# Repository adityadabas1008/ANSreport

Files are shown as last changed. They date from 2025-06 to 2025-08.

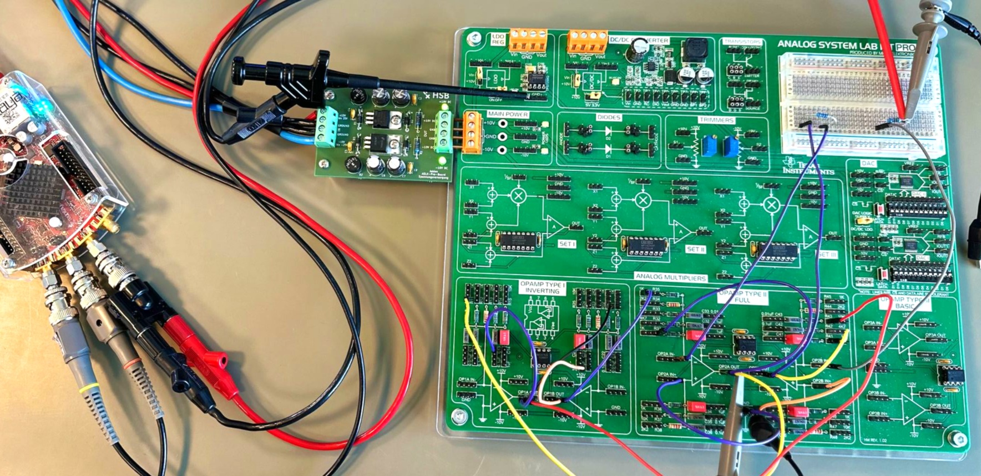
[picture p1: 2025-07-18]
_manuscript/images/Realaufbau.jpg

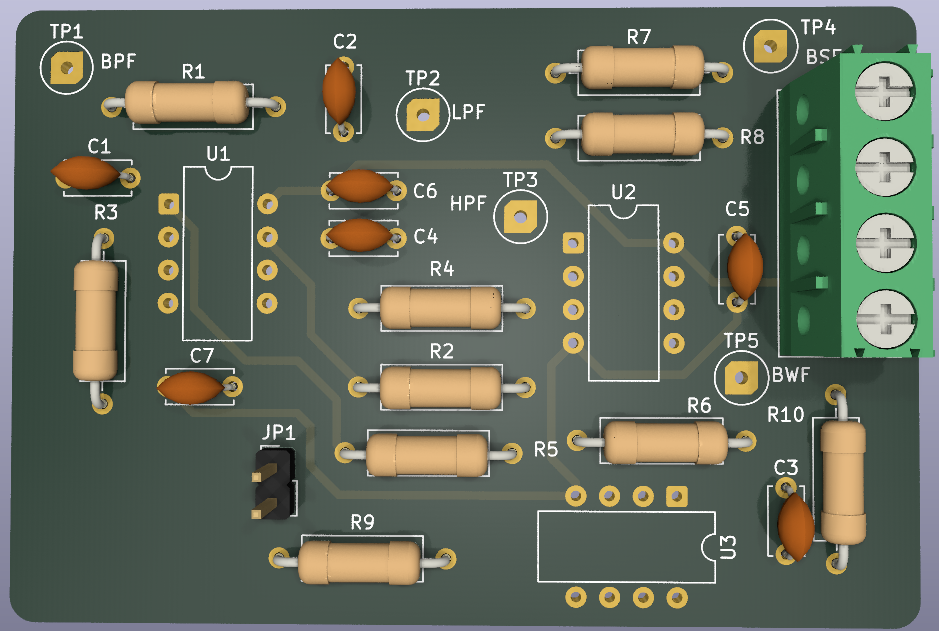
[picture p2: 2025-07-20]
_manuscript/images/pcbv1.png

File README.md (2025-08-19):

# ANSreport

Hello there! Welcome to the ANSreport repository.

This repository is a combined work of the students of the course "Analoge Schaltungen" from the Hochschule Bremen, under the mentorship of **Prof. Dr. Mirco Meiners**.

The contributors are:
- Aditya Dabas
- Adrian Jauch
- Mohamad Wehbi

What you see here is a quarto report of a project from the 'Texas Instruments Analog Circuits Lab Kit' manual.

The project aimed at building deeper understanding of analog circuits using the universal biquad filter design.
Here, we implemented the second order biquad filter in three different stages:
1. **The theory level**: Here, we explored the ideal world of Electronics by simulating the circuit in KiCAD.
2. **Filter on a discrete circuit design**: After that the circuit was build on the lab board of ASLK using jumper wires, was somewhat imperfect, but still worked.
3. **The integrated PCB Design**: Then we wanted to explore the PCB design of the circuit, so we designed the biquad filter on a PCB, in a compact form and checked the functionality in the lab, we also tried to expand the circuit by adding another order to our second order filter, by cascading a second order filter to another butterworth filter to get a third order filter and a cleaner curve.

Now, its upto you to explore the interesting results we got in the ideal world and the real world of electronics.
Another question would be, were we able to successfully cascade the second order filter to a third order filter to get the butterworth output ? was it successful on the compact PCB we designed ?

Run the report to find out!

Please note that the report is in German, as it was a project for a German course.

## How to run the report
1. Clone the repository as it is.
2. Choose the editor of your choice, e.g. [VSCode](https://code.visualstudio.com/).
3. Make sure you have [quarto](https://quarto.org/docs/get-started/) installed.
4. Just render the index.qmd file in the editor.

Voila! You should see the report in your browser.

Thank you for your interest in our project!

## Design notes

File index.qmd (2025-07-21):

---
title: "Entwurf und PCB Design eines universellen Biquad Filters"
author: 
  - name: Aditya Dabas
    orcid: 0009-0001-5679-9910
    email: adabas@stud.hs-bremen.de
    corresponding: true
    roles: "Lead author"
    affiliation: Hochschule Bremen - City University of Applied Sciences (HSB)

  - name: Mohamad Wehbi
    orcid: 
    email: mwehbi@stud.hs-bremen.de
    corresponding: true
    roles: "Lead author"
    affiliation: Hochschule Bremen - City University of Applied Sciences (HSB)

  - name: Adrian Jauch
    orcid: 
    email: ajauch@stud.hs-bremen.de
    corresponding: false
    roles: "Lead author"
    affiliation: Hochschule Bremen - City University of Applied Sciences (HSB)

affiliation:
  -  name: Hochschule Bremen - City University of Applied Sciences (HSB)
     city: Bremen
     state: Germany
     url: https://www.hs-bremen.de  

keyword:
  - Filter Design 
  - PCB

abstract: |
  In diesem Projekt wurde ein universeller Biquad-Filter entworfen und als Leiterplatte (PCB) umgesetzt. Ziel war es, die theoretischen Grundlagen zu analysieren, verschiedene Filtertypen zu simulieren und die praktische Realisierung zu dokumentieren. Die Charakterisierung und Messauswertung des aufgebauten Filters zeigen die Übereinstimmung zwischen Theorie und Praxis. Der gesamte Entwicklungsprozess – von der Schaltungsauslegung bis zum fertigen PCB – wird nachvollziehbar dargestellt.

date: last-modified
bibliography: references.bib
# csl: ieee-with-url.csl
# fig-numbering: true 
---

{{< include content/_sec_Motivation.qmd >}}
{{< include content/_sec_Theorie.qmd >}}
{{< include content/_sec_Filter.qmd >}}
{{< include content/_sec_Charakterisierung.qmd >}}
{{< include content/_sec_Messauswertung.qmd >}}
{{< include content/_sec_PCB_Entwurf.qmd >}}
{{< include content/_sec_Fazit.qmd >}}
{{< include content/references.qmd >}}

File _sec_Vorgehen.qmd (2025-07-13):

# Vorgehen

Was haben wir von anfang an bis jetzt gemacht ?

1. Anti Aliasing Fliter
2. Filter entwurf mit RLC Glied, TP, HP, BP
3. Einführung in die Biquads
4. ASLK Lab Manual - Labor 4 gelesen, Spezifikation gelesen, Schaltung gesehen, Ziel des Projekts festgelegt
5. Spezifikation für die Schaltung: Durch Kreisfrequenzen R , C werte und Kreisfrequenz f berechnet, Güte Faktor miteinbezogen 
6. Simulation auf KiCAD durchgeführt, Plots mit dem Manual verglichen
7. Schaltungsaufbau auf dem ASLK Board mit Kabeln
8. RedPitaya integriert für Messung und Auswertung der Schaltung (Bode-Plot und Messwerte)
9. Schaltungsverhalten unerwartet, dann die Schaltung überprüft (gemerkt: Kabelnstecken ist eine Fehlerquelle)
10. Messung erneut düchgeführt, mussten nochmal schaltüng überprüfen
11. Das Problem war ASLK Board und nicht der Aufbau, rausgefunden indem: die Schaltung vom Laboring überprüfen lassen
12. Die Schaltung neu aufbaut, mit dem neuen Board und ohne Kabeln zu verlängern (keine 2 Kabeln zusammengesteckt)
13. Nochmal gemessen und erwartete Ergebnisse bekommen. (Bestätigt - Board war das Problem)
14. Messwerte aufgenommen mit adäquat Datenmanagement und entsprechende Spezifikationen
15. Nach ASLK Manual Aufgaben gemacht und die Messwerte aufgenommen, leichte änderung an der Schaltung je nach Aufgabenstellung
16. Bode Plot analysiert um Verhalten von Filtern zu überprüfen, -20dB Dämpfung in der Amplitude rausgefunden
17. Fehler Suche: Wiederstände überprüft und die auf dem Board gemessen mit Multimeter, festgestellt: R6 war 10k Ohm anstatt 1k Ohm
18. RedPitaya auf HV gestellt, um Peak Messwerte richtig zu bekommen
19. Messungen erneut aufgenommen, Fehler beseitigt
20. Schaltung mit einer weiteren Ordnung Erweitert: Butterworth Filter in der Schaltung eingebaut, Übertragungsfunktionen hergeleitet
21. Die erweiterte Schaltung simuliert: Erwartete Ergebnisse bekommen
22. Schaltung auf dem Steckbrett entsprechend der Simulation erweitert und gemessen: Auch gute Ergebnisse bekommen
23. Schaltung war jetzt bereit für ein Leiterplattendesign
24. 3 Variante von PCB design mit Verbesserungen in jeder Transition
25. PCB Design erwitert für 2 Schaltungmöglichkeiten
26. Design Überprüfen lassen vom LaborING und dann die Platine bestellt
27. Platine gefertigt, gemessen, Messwerte für den Vergleich mit Redpitaya aufgenommen

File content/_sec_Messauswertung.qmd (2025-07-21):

# Messung und Analyse

Nachdem wir die Biquad-Filter-Schaltung bereits erfolgreich auf dem ASLK Pro Board aufgebaut haben, lag der Fokus dieses Abschnitts auf der Durchführung der Messungen und der anschließenden Auswertung der Ergebnisse. Ziel war es, die realen Frequenzgänge der verschiedenen Filtertypen experimentell zu erfassen und diese mit den zuvor durchgeführten Simulationen zu vergleichen.

## Messungsschritte {.unnumbered}

Für die experimentelle Ermittlung des Frequenzgangs wurde die Schaltung mithilfe der grafischen Oberfläche des Red Pitaya vermessen.

Die so gewonnenen Messdaten wurden im Anschluss exportiert und zur weiteren Analyse mit einem eigens entwickelten Python-Skript ausgewertet. Dadurch war es möglich, die Amplituden- und Phasengänge der real aufgebauten Schaltung systematisch mit den Simulationskurven zu vergleichen.

## Vergleich Simulation vs. Diskret
Zur Bewertung der praktischen Umsetzung wurden die Messergebnisse der real aufgebauten Schaltung mit den zuvor durchgeführten Simulationen verglichen. Für beide Gütefaktoren ($Q=1$ und $Q=10$) wurden jeweils die Frequenzgänge der vier Filtertypen (Tiefpass, Hochpass, Bandpass und Bandsperre) aufgenommen und grafisch gegenübergestellt.

### Für $Q=1$ {.unnumbered}

### -Bandpass {.unnumbered}

Bode-Plot Vergleich des simulierten- und des auf dem Board Bandpassfilters für $Q = 1$.

Die Simulation-Messung liefert einen klar definierten Resonanzpeak mit sehr gleichmäßigen Flanken. Die diskrete Variante zeigt den Peak geringfügig verschoben und weist an den Flanken kleine Unregelmäßigkeiten auf, wodurch der Verlauf etwas unschärfer erscheint.

### -Bandstop {.unnumbered}

Bode-Plot Vergleich des simulierten- und des auf dem Board Bandstopfilters für $Q = 1$.

Der Einbruch der Bandsperre zeichnet sich durch eine besondere Tiefe und flache, saubere Flanken aus. Bei einem diskreten Aufbau ist die Dämpfung durchaus vergleichbar, jedoch treten an den Rändern leichte Sprünge und geringfügige Ungenauigkeiten auf.

### -Hochpass {.unnumbered}

Bode-Plot Vergleich des simulierten- und des auf dem Board Hochpassfilters für $Q = 1$.

Der Hochpass auf der Simulation steigt bis zur Eckfrequenz ohne Störungen an und fällt danach konstant mit –20 dB/Dekade ab. Der diskrete Versuchsaufbau hinkt diesem Anstieg minimal hinterher und zeigt punktuelle Ausreißer bei etwa $50 Hz$ und $100 Hz$.

### -Tiefpass {.unnumbered}

Bode-Plot Vergleich des simulierten- und des auf dem Board Tiefpassfilters für $Q = 1$.

Beim Tiefpass fällt die Simulation-Kurve bis zur Eckfrequenz ideal flach ab und nimmt dann homogen –40 dB/Dekade an. Die diskrete Schaltung weist um die Eckfrequenz ein leichtes Überschwingen und vereinzelt kleine Unebenheiten im Sperrbereich auf.

### Für $Q=10$ {.unnumbered}

### -Bandpass {.unnumbered}

Bode-Plot Vergleich des simulierten- und des auf dem Board Bandpassfilters für $Q = 10$.

Der starke Resonanzpeak ist deutlich ausgeprägt, jedoch sehr gleichmäßig. Im diskreten Aufbau fällt der Peak minimal tiefer aus, wirkt aber an der Spitze etwas unruhig und leicht gezackt.

### -Bandstop {.unnumbered}

Bode-Plot Vergleich des simulierten- und des auf dem Board Bandstopfilters für $Q = 10$.

Bei der Bandsperre ist der Einbruch auf der Board geringfügig flacher, dafür allerdings äußerst stabil und glatt. Die Simulation Kurve erreicht eine etwas tiefere Dämpfung.

### -Hochpass {.unnumbered}

Bode-Plot Vergleich des simulierten- und des auf dem Board Hochpassfilters für $Q = 10$.

Die Simulation zeigt einen idealen Anstieg bis zur Grenzfrequenz und einen konstanten Verlauf darüber hinaus. Im diskreten Aufbau ist der Anstieg etwas flacher, und es treten leichte Unregelmäßigkeiten im Bereich um $100\,\mathrm{Hz}$ auf.

### -Tiefpass {.unnumbered}

Bode-Plot Vergleich des simulierten- und des auf dem Board Tiefpassfilters für $Q = 10$.

Die Simulation zeigt einen idealen Abfall nach der Grenzfrequenz mit einer Steilheit von –40 dB/Dekade. Im diskreten Aufbau ist der Abfall etwas weniger steil, und es treten leichte Unregelmäßigkeiten im Sperrbereich auf.

## Interpretation der Messergebnisse

Insgesamt zeigen die Plots, dass die gemessenen Frequenzgänge der realen Schaltung den simulierten Kurven in ihrem grundsätzlichen Verlauf gut entsprechen. Die charakteristischen Eigenschaften der jeweiligen Filtertypen (Bandpass, Bandsperre, Hochpass, Tiefpass) sind sowohl in Simulation als auch in der Messung klar erkennbar.

Die beobachteten Abweichungen zwischen Simulation und Messung sind hauptsächlich auf Bauteiltoleranzen sowie Einflüsse der verwendeten Messkabel zurückzuführen. Nicht ideale Kontakte, Toleranzen der Bauteile oder Kabel können das Messergebnis beeinflussen. Zudem können Unterschiede in der Frequenzauflösung oder fehlende Messwerte in bestimmten Bereichen zu Abweichungen führen, insbesondere wenn Messung und Simulation nicht exakt dieselben Frequenzen abdecken.

Zusammenfassend bestätigen die Messergebnisse die prinzipielle Funktionsweise der Filter, zeigen aber auch die Grenzen idealisierter Simulationen im Vergleich zur realen Schaltungspraxis auf.

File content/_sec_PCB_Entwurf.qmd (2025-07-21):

# Umsetzung als Leiterplatte
Die Umsetzung der Biquad-Schaltung auf eine gedruckte Leiterplatte (PCB) verfolgt mehrere Ziele: 
Erstens erhöht eine professionelle Leiterplatte die mechanische Stabilität und Wiederholgenauigkeit im Vergleich zu Jumperkabel-Versuchen. 
Zweitens minimiert eine sorgfältig geroutete Platine parasitäre Effekte (Leitungsinduktivitäten, -kapazitäten), die bei langen, unkontrollierten Kabelwegen auftreten. 
Drittens erlaubt die PCB eine kompakte, übersichtliche Integration aller Filterzweige, sodass verschiedene Eckfrequenzen oder Gütefaktoren per Jumper umgeschaltet werden können, ohne das Board komplett neu aufzubauen.

## Vorgehensweise im Layoutprozess

1. **Auswahl der Basis-Topologie**  
   Zunächst wurde die einfachste Biquad-Schaltung für Güte $Q=1$ mit Eckfrequenz $\approx 160\,\mathrm{Hz}$ in KiCad aufgebaut.

2. **Footprint-Zuordnung**  
   Für alle Bauteile (Operationsverstärker im DIL-Sockel, Widerstände, Kondensatoren, Jumper) wurden passende Footprints manuell ausgewählt. DIL-Sockel ermöglichen den einfachen Ein- und Ausbau der OP-Amps.

3. **Erweiterung um Schaltoptionen**  
   Um Messungen bei zwei unterschiedlichen Gütefaktoren und zwei Eckfrequenzen zu ermöglichen, wurden Jumper-Pads vorgesehen, mit denen man:  
   - zwischen $Q=1$ und $Q=10$ umschalten  
   - die Eckfrequenz durch Parallelschaltung unterschiedlicher RC-Glieder wechseln  
   - den LPF-Ausgang als Eingang für die 3. Ordnung–Butterworth-Stufe aktivieren kann  

4. **Platzoptimierung**  
   Das erste Layout maß ca. 5 cm × 7 cm (siehe @fig-pcbv1), war aber zu unflexibel. Das erweiterte Design kam auf 5 cm × 8 cm(siehe @fig-pcbs). Dabei war uns wichtig:  
   - **Bauteilenah**: Kurze Verbindungen zwischen OP-Amp-Pins und zugehörigen RC-Netzwerken reduzieren parasitäre L- und C-Effekte.  
   - **Abwinkelung**: Leiterbahnen wurden nur mit maximal $45^\circ$-Ecken geroutet, um Reflexionen und Signalverzerrungen bei höheren Frequenzen zu minimieren.  
   - **Layernutzung**: Das Top-Layer für Signal- und Strompfade, das Bottom-Layer vollständig als durchgehende Massefläche („Ground Plane“) reserviert. So entfallen separate GND-Drähte. 
   - **Decoupling**: An jeder Spannungsversorgung des TL082 wurde $100\,\mathrm{nF}$ Kondensatoren nahe den OP-Amp-Pins platziert, um Versorgungsspannungsspitzen und Rauschen zu unterdrücken.

   PCB-Design Version 1

---

### Design-Verbesserungen und Begründungen {.unnumbered}

1. **Bauteilwertebeschriftung**  
   Jeder Widerstand und Kondensator erhielt eine Referenz („R1“, „C3“) und einen Wertaufdruck auf der Silkscreen-Schicht. Fehlt dies, kann beim Bestücken leicht verwechselt werden.

2. **Fehlender GND-Pins**  
   Auf dem PCB fehlte Ground-Pins. Dadurch war es schwer, während der Messung eine sichere Masseverbindung herzustellen. Wir haben das provisorisch durch manuelles Bohren von zwei Löchern und den Einbau von Pins zur Groundplane behoben.

3. **Jumper als Fehlerquelle**  
   Die mechanischen Jumper auf dem Board sind zwar flexibel, können aber ähnliche Störeffekte wie Jumperkabel verursachen und Messungenauigkeiten einführen.

::: {#fig-pcbs layout-ncol=2}

Fertiges PCB-Design

Fertige PCB

Fertige Bi-Quad Filter Platine
:::

### Zusammenfassung und Ausblick {.unnumbered}

Mit diesem PCB-Design haben wir eine kompakte, reproduzierbare Plattform geschaffen, um Biquad-Filter mit variabler Güte und Eckfrequenz zu charakterisieren und bei Bedarf um eine Butterworth-Stufe 3. Ordnung zu ergänzen. 
Für künftige Revisionen empfehlen sich:  
- Vollständige Beschriftung aller Werte auf der Platine  
- Einheitliche GND Pins 
- Integration von SMD-Schaltern statt Jumpern 

Damit wird die Platine für die Lehrzwecke gut geeignet.

## Messungen an der PCB-Schaltung

Im Anschluss an das Layout und die Fertigung der Platine wurden die Übertragungs­funktionen aller Filterausgänge mit dem Red Pitaya Mess­system aufgenommen. Die Signale wurden über einen Frequenz­sweep für verschiedene Frequenzen eingespeist und die Amplituden- sowie Phasengänge mit einem eigens entwickelten Python-Skript ausgewertet und geplottet.  

## Vergleich: Diskret vs. PCB {.unnumbered}

Im Folgenden sind die Bode-Diagramme der diskreten Versuchsaufbauten (auf dem ASLK PRO Board mit Jumperkabeln) gegenüber den Messergebnissen der fertigen PCB-Schaltung dargestellt. Dieser Vergleich zeigt, inwieweit das PCB-Layout die Filtercharakteristik stabilisiert. 

### Für \(Q = 1\) {.unnumbered}

### Bandpass {.unnumbered}

Bode-Plot Vergleich des auf dem Board- und des auf dem PCB Bandpassfilters für \(Q = 1\).

Die PCB-Messung liefert einen klar definierten Resonanzpeak mit sehr gleichmäßigen Flanken. Die diskrete Variante zeigt den Peak geringfügig verschoben und weist an den Flanken kleine Unregelmäßigkeiten auf, wodurch der Verlauf etwas unschärfer erscheint.

### Bandstop {.unnumbered}

Bode-Plot Vergleich des auf dem Board- und des auf dem PCB Bandstopfilters für \(Q = 1\).

Der Einbruch der Bandsperre auf der Platine zeichnet sich durch eine besondere Tiefe und flache, saubere Flanken aus. Bei einem diskreten Aufbau ist die Dämpfung durchaus vergleichbar, jedoch treten an den Rändern leichte Sprünge und geringfügige Ungenauigkeiten auf.

### Hochpass {.unnumbered}

Bode-Plot Vergleich des auf dem Board- und des auf dem PCB Hochpassfilters für \(Q = 1\).

Der Hochpass auf der PCB steigt bis zur Eckfrequenz ohne Störungen an und fällt danach konstant mit –20 dB/Dekade ab. Der diskrete Versuchsaufbau hinkt diesem Anstieg minimal hinterher und zeigt punktuelle Ausreißer bei etwa 50 Hz und 100 Hz.

### Tiefpass {.unnumbered}

Bode-Plot Vergleich des auf dem Board- und des auf dem PCB Tiefpassfilters für \(Q = 1\).

Beim Tiefpass fällt die PCB-Kurve bis zur Eckfrequenz ideal flach ab und nimmt dann homogen –40 dB/Dekade an. Die diskrete Schaltung weist um die Eckfrequenz ein leichtes Überschwingen und vereinzelt kleine Unebenheiten im Sperrbereich auf.

---

### Für \(Q = 10\) {.unnumbered}

### Bandpass {.unnumbered}

Bode-Plot Vergleich des auf dem Board- und des auf dem PCB Bandpassfilters für \(Q = 10\).

Der starke Resonanzpeak der Platine ist deutlich ausgeprägt, jedoch sehr gleichmäßig. Im diskreten Aufbau fällt der Peak minimal höher aus, wirkt aber an der Spitze etwas unruhig und leicht gezackt.

### Bandstop {.unnumbered}

Bode-Plot Vergleich des auf dem Board- und des auf dem PCB Bandstopfilters für \(Q = 10\).

Bei der Bandsperre ist der Einbruch auf der PCB geringfügig flacher, dafür allerdings äußerst stabil und glatt. Die diskrete Kurve erreicht eine etwas tiefere Dämpfung, zeigt jedoch in der Nähe des Einbruchs leichte Unregelmäßigkeiten.

### Hochpass {.unnumbered}

Bode-Plot Vergleich des auf dem Board- und des auf dem PCB Hochpassfilters für \(Q = 10\).

Im Hochpassbereich tritt die PCB-Resonanzspitze leicht verzögert auf, bleibt dabei aber sehr sauber. Die diskrete Schaltung erreicht die Spitze ein wenig früher, ist dabei jedoch im Anstieg geringfügig weniger gleichmäßig.

### Tiefpass {.unnumbered}

Bode-Plot Vergleich des auf dem Board- und des auf dem PCB Tiefpassfilters für \(Q = 10\).

Der Tiefpass auf der Platine bildet den Peak etwas nachlaufend und etwas flacher als die Simulation ab. Der diskrete Aufbau zeigt einen schärferen, früheren Peak, dessen Flanken an einzelnen Frequenzen kleine Sprünge aufweisen.

### Diskussion der Ergebnisse: {.unnumbered}

Beim Vergleich der Bode-Diagramme (rote Kurven = diskret, blaue = PCB) ergeben sich folgende allgemeine Beobachtungen:

- **Amplitude-Verschiebung**  
  - Für \(Q=1\) liegt die PCB-Amplitude tendenziell leicht vor (Vorsprung um wenige Hertz) gegenüber dem diskreten Aufbau.  
  - Für \(Q=10\) zeigt die PCB eine kleine Verzögerung (nachlaufender Peak) um wenige Hertz.  
- **Kurvenglätte**  
  Die PCB-Daten verlaufen insgesamt glatter. Die im Diskret-Aufbau auftretenden kleinen Ausreißer entfallen, da das PCB parasitäre Effekte reduziert.  
- **Sampling-Artefakte**  
  An einigen Stellen wirken die Kurven „eckig“ – hier lagen zu wenige Messpunkte vor, was die Interpolation weniger stufenlos erscheinen lässt.

---

## Vergleich: Ideal vs. PCB {.unnumbered}

### Für $Q=1$ {.unnumbered}

<!--
::: {layout-nrow=2}
![Bandpass](platine_real_vergleich\Q1\Bandpass.png){#fig-pcbsimbpf1 width=100%}

![Bandstop](platine_real_vergleich\Q1\Bandstop.png){#fig-pcbsimbpf2 width=100%}

![Hochpass](platine_real_vergleich\Q1\Hochpass.png){#fig-pcbsimbpf3 width=100%}

![Tiefpass](platine_real_vergleich\Q1\Tiefpass.png){#fig-pcbsimbpf4 width=100%}
:::
-->

### Bandpass {.unnumbered}

Bode-Plot Vergleich des simulierten- und des auf dem PCB Bandpassfilters für $Q = 1$.

Die gemessene PCB-Kurve folgt der Simulation nahezu perfekt. Resonanzfrequenz und Peak-Amplitude stimmen überein, die PCB zeigt nur minimale Glättungsdifferenzen im Flankenbereich.

### Bandstop {.unnumbered}

Bode-Plot Vergleich des simulierten- und des auf dem PCB Bandstopfilters für $Q = 1$.

Simulation und Platine liegen im Sperrbereich deckungsgleich. Der Einbruchstiefpunkt und die Flankensteilheit stimmen fast überein.

### Hochpass {.unnumbered}

Bode-Plot Vergleich des simulierten- und des auf dem PCB Hochpassfilters für $Q = 1$.

Die Amplitude und Phase der PCB fallen identisch zu den simulierten Kennlinien ab. Lediglich im sehr hohen Frequenzbereich (< 1 dB Abweichung) ist die PCB-Zeitkonstante leicht weicher.

### Tiefpass {.unnumbered}

Bode-Plot Vergleich des simulierten- und des auf dem PCB Tiefpassfilters für $Q = 1$.

Auch hier liegen Messung und Simulation fast auf demselben Verlauf. Der kleine Peak um die Eckfrequenz zeigt sich auf der Platine ebenso deutlich und mit derselben Steilheit.

### Für $Q=10$ {.unnumbered}

### Bandpass {.unnumbered}

Bode-Plot Vergleich des simulierten- und des auf dem PCB Bandpassfilters für $Q = 10$.

Bei der Simulation liegt der Resonanzpeak etwas schärfer und minimal später, während die PCB-Messung einen etwas flacheren, leicht vorgezogenen Peak zeigt. Die Bandbreite ist sehr vergleichbar, die PCB-Kurve wirkt insgesamt glatter.

### Bandstop {.unnumbered}

Bode-Plot Vergleich des simulierten- und des auf dem PCB Bandstopfilters für $Q = 10$.
 
Der tiefe Einschnitt der Simulation erscheint stärker. Die PCB-Kurve weist einen flacheren Verlauf auf, was auf die begrenzte Messpunktdichte zurückzuführen sein kann. Es ist anzunehmen, dass die Kurve bei einer höheren Anzahl an Messpunkten auch bei PCB tiefer verlaufen würde.

### Hochpass {.unnumbered}

Bode-Plot Vergleich des simulierten- und des auf dem PCB Hochpassfilters für $Q = 10$.

In der Simulation führt der Hochpass-Peak knapp vor der Eckfrequenz zu einer leicht ausgeprägteren Spitze; die PCB-Messung eilt ihr minimal hinterher. Im Sperrbereich verläuft die PCB-Kurve etwas ruhiger.

### Tiefpass {.unnumbered}

Bode-Plot Vergleich des simulierten- und des auf dem PCB Tiefpassfilters für $Q = 10$.

Auch beim Tiefpass findet sich in der Simulation ein etwas ausgeprägteres Peak-Overshoot, während die PCB-Messung den Peak minimal verzögert wiedergibt. Die Abfallflanke ist auf beiden Kurven nahezu identisch.

## Butterworth Filter Vergleich:  Simulation vs. PCB {.unnumbered}

Bode-Plot Vergleich des simulierten- und des auf dem PCB Butterworth-Filters 3. Ordnung.

Die gemessene PCB-Kurve des Butterworth-Filters folgt der Simulation sehr genau. Die Übergangsfrequenz und die Flankensteilheit stimmen gut überein. Kleine Abweichungen in der Amplitude und eine minimal geglättete Flanke auf der Platine sind auf Messauflösung und parasitäre Effekte zurückzuführen.

**Allgemeine Beobachtung:**  
Die PCB-Messdaten folgen dem idealen Simulationsverlauf sehr eng, lediglich kleine Frequenzverschiebungen und glattere Flanken auf der Platine fallen auf. Die geringere Tiefe im Bandsperr-Einschnitt und der leicht vor- bzw. nachlaufende Resonanzpeak sind wahrscheinlich auf die endliche Anzahl von Messpunkten und minimale Layout-Parasitär­effekte zurückzuführen.

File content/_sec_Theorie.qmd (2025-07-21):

# Theoretischer Hintergrund

Im folgenden Teil gehen wir auf die Theorie ein, auf Grundlagen welcher wir an dem Labor gearbeitet haben 

## Grundlagen zu analogen Filtern
Zunächst haben wir uns mit dem Aufbau analoger Filter beschäftig, um genauer zu sein mit FIltern welche RLC Glieder haben. Das $R$ steht für den Widerstand, das $L$ steht für die Induktivität und das $C$ für den Kondensator.

Jenachdem wie man die einzelnen Bestandteile anordnet, kann man Vier verschiedene Filter entwerfen, einen Hochpass, einen Tiefpass, einen Bandpass und einen Bandstop.

Ein wichtiger Faktor für diese Filter ist die Grenzfrequenz. Diese Hilft einem dabei den Frequenzbereich, welcher für einen von Interesse ist, zu ermitteln, da an der Grenzfrequenz der Filter eine Änderung, je nach Filter, durchläuft.

Bei einem Hochpassfilter werden jegliche Frequenzen vor der Grenzfrequenz gefilter und jegliche Frequenzen nach der Grenzfrequenz durchgelassen.

Der Tiefpassfilter ist das genaue Gegenteil des Hochpassfilters, jegliche Frequenzen vor der Grenzfrequenz werden durchgelasse und jegliche danach gefilter.

Der Bandpassfilter filtert vor und nach der Grenzfrequenz jegliche Frequenzen und lässt die Grenzfrequenz passieren.

Der Bandstopfilter ist das genaue Gegenteil vom Bandpassfilter und lässt jede Frequenz passieren bis auf die Grenzfrequenz.

### Übertragungsfunktionen und verschiedene Filtertypen {.unnumbered}

Nachdem die Grundlegenden Eigenschafften der Filter bestimmt waren, haben wir uns noch um die Übertragungsfunktion und der RC Schaltung von dem Tiefpass- und HochpassFilter beschäftigt.

RC Schaltung von Hoch- und Tiefpassfilter.[@RCSchaltung]

Es ist zu sehen, dass der Hochpass- und Tiefpassfilter sich in der Anordnung unterscheiden, R und C werden miteinander ausgetauscht.
Daraufhin haben wir die Übertragungsfunktionen der beiden Filter bestimmt.

Dabei ist die folgende Übertragungsfunktion für den Hochpassfilter herausgekommen:
$$
H(s) = \frac{sRC}{1 + sRC}
$$

Und die folgende Übertragungsfunktion für den Tiefpass Filter:

$$
H(s) = \frac{1}{1 + sRC}
$$

## Anti Aliasing Filter

Bei allen Messungen im Rahmen dieses Projekts wurde das Messsystem **RedPitaya** eingesetzt. Da RedPitaya ein digitales Oszilloskop ist und die Signale zur weiteren Verarbeitung digitalisiert, spielt der sogenannte **Anti-Aliasing-Filter** eine wichtige Rolle.

Ein **Anti-Aliasing-Filter** ist ein analoger Tiefpassfilter, der direkt vor dem Analog-Digital-Wandler (ADC) platziert wird. Seine Aufgabe ist es, alle Frequenzanteile oberhalb der halben Abtastfrequenz (Nyquist-Frequenz) ausreichend zu dämpfen.
Ohne einen solchen Filter würden hohe Frequenzanteile im Eingangssignal beim Digitalisieren als niedrigere Frequenzen ("Aliasing-Effekte") erscheinen und die Messung verfälschen.

**Aber was bedeutet das für uns?**

Bevor das Signal von RedPitaya digitalisiert und aufgezeichnet wird, sorgt ein vorgeschalteter Tiefpass (Anti-Aliasing-Filter) dafür, dass nur Signalanteile im relevanten Frequenzbereich erfasst werden. Das schützt vor Messfehlern und stellt sicher, dass die Analyse der Filter (z.B. Biquad, Butterworth) korrekt durchgeführt werden kann.

## Grundlagen Biquad-Filter

Ein **Biquad-Filter** ist eine universelle, aktive Filterstruktur zweiter Ordnung, die in einer Vielzahl von Anwendungen zur Realisierung unterschiedlicher Filtertypen wie Tiefpass, Hochpass, Bandpass und Bandsperre eingesetzt wird. Die Bezeichnung „Biquad“ leitet sich vom englischen Begriff „biquadratic“ ab und bezieht sich auf die quadratische Form des Nennerpolynoms in der Übertragungsfunktion, was die zweite Ordnung des Filters kennzeichnet.

Die typische Realisierung eines Biquad-Filters erfolgt mittels zweier gekoppelter Operationsverstärkerstufen, die über spezifisch ausgelegte Rückkopplungs- und Durchkopplungsnetzwerke miteinander verbunden sind. Diese Anordnung ermöglicht es, das gewünschte Übertragungsverhalten bereits mit einem vergleichsweise geringen Bauteilaufwand umzusetzen. Durch gezielte **Auswahl der Widerstands- und Kapazitätswerte** lassen sich charakteristische Parameter wie **Grenzfrequenz** und **Gütefaktor (Q)** präzise einstellen, sodass verschiedene Filtercharakteristika, beispielsweise **Butterworth** (maximale Flachheit im Durchlassbereich), Tschebyscheff (ausgeprägte Flankensteilheit mit Welligkeit) oder Bessel (maximale Linearität der Gruppenlaufzeit), realisierbar sind.

Die allgemeine Übertragungsfunktion eines Biquad-Filters lautet:

$$
H(s) = \frac{b_0 + b_1 s + b_2 s^2}{a_0 + a_1 s + a_2 s^2}
$$

Hierbei werden die Koeffizienten $b_i$ und $a_i$ durch die konkrete Wahl der Widerstands- und Kondensatorwerte festgelegt. Die verschiedenen Filtertypen unterscheiden sich lediglich in den spezifischen Koeffizientenwerten, während die zugrunde liegende Schaltungsstruktur identisch bleibt. Beispielsweise resultiert ein reiner Bandpass bei $b_0 = b_2 = 0$, $b_1 \neq 0$, während bei $b_1 = 0$ und $b_0 = b_2 \neq 0$ eine Bandsperre realisiert wird.

Ein wesentlicher Vorteil des Biquad-Konzepts liegt in seiner Modularität. Durch die serielle oder parallele Verschaltung mehrerer identischer Biquad-Stufen lassen sich problemlos Filter höherer Ordnung aufbauen, ohne dass die Komplexität jeder einzelnen Stufe zunimmt. Zudem ermöglicht die separate Kalibrierbarkeit jeder Stufe eine exakte Justierung von Gütefaktor und Grenzfrequenz, wodurch Fertigungstoleranzen gezielt kompensiert werden können. Aufgrund dieser Flexibilität und der vergleichsweise einfachen Implementierung haben sich Biquad-Filter als Standardlösung in vielen Bereichen etabliert, etwa in der Audio- und Messtechnik sowie in der industriellen Signalverarbeitung.[@FILTERS07]

## Gütefaktor Q und Einfluss

Der Gütefaktor $Q$ beschreibt bei Zweitordnungs-Filtern, wie scharf die Resonanz um die Mittenfrequenz $\omega_0$ ausgebildet ist. Ein hoher $Q$-Wert erzeugt eine steilere Flankensteilheit und – bei Bandpass- oder Bandsperre-Charakteristik – einen ausgeprägteren Resonanzbuckel. Mathematisch ergibt sich für die Standard-Übertragungsfunktion eines Zweitordnungs-Tiefpass:

$$
H(s) \;=\; \frac{1}{1 + \frac{s}{\omega_{0} Q} + \left(\frac{s}{\omega_{0}}\right)^{2}}
$$

Hier bestimmt $Q$ gemeinsam mit $\omega_0$ die Lage und Streuung der beiden komplexen Polstellen:

$$
s_{1,2} \;=\; -\frac{\omega_{0}}{2Q} \;\pm\; j\,\omega_{0}\,\sqrt{\,1 - \frac{1}{4Q^{2}}\,}\;.
$$

Für den ideal „maximal flachen“ Butterworth-Fall wählt man $Q = 1/\sqrt{2} \approx 0{,}707$, wodurch kein Durchtritts-Peaking auftritt und die Flankensteilheit $-20\ \mathrm{dB/Dekade}$ beträgt (das heißt: Eine Verzehnfachung der Frequenz führt zu einem Pegelabfall von 20 dB). [@lecture20]

In der KHN-Biquad-Topologie wird der Gütefaktor jedes Teilpfads (Tiefpass, Bandpass, Hochpass, Bandsperre) direkt über das Verhältnis ausgewählter Widerstände eingestellt. Durch Variation dieser Widerstandsrelation lässt sich $Q$ unabhängig von der Eckfrequenz $\omega_0$ justieren – man gewinnt also Kontrolle über die Schärfe der Filtercharakteristik, ohne die Mittenfrequenz zu verändern. Ein niedriger $Q$-Wert führt zu einem breiten, sanft abfallenden Übergang, während ein hoher $Q$-Wert die Flanken steiler macht und bei Bandpass- oder Bandsperre-Ausgängen zusätzlich einen ausgeprägten Resonanzbuckel erzeugt.

In diesem Versuch wurden die Gütefaktoren $Q = 1$ und $Q = 10$ eingestellt und das jeweilige Verhalten der Filterausgänge entsprechend beobachtet.

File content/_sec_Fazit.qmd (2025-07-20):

# Fazit und Ausblick

Im Rückblick auf das Labor können wir festhalten, dass wir unsere Ziele erfolgreich erreicht haben. Das im Studium erworbene Wissen konnten wir gezielt einsetzen, um ein eigenes Platinen-Design zu entwickeln. Damit haben wir nicht nur die gestellten Anforderungen erfüllt, sondern auch wertvolle praktische Erfahrungen gesammelt.

Natürlich verlief nicht alles reibungslos. Zu Beginn funktionierte unsere Steckbrett-Schaltung nicht, was uns zur Fehlersuche zwang. Letztlich stellte sich heraus, dass das Problem nicht an der Schaltung selbst, sondern am Steckbrett lag.

Leider mussten wir feststellen, dass eigene Fehler aufgetreten sind. So verwendeten wir versehentlich einen $10\,k\Omega$-Widerstand anstelle eines $1\,k\Omega$-Widerstands, was zu einer unerwünschten Dämpfung führte. Nachdem wir diesen Fehler identifiziert hatten, konnten wir ihn beheben. Solche Erfahrungen haben uns gezeigt, wie wichtig sorgfältiges Arbeiten und wiederholtes Überprüfen sind – selbst kleine Unachtsamkeiten können große Auswirkungen haben.

Trotz dieser Herausforderungen überwiegen die positiven Ergebnisse. Unser Platinen-Design funktioniert wie geplant, und die einzelnen Filter zeigen den gewünschten Frequenzverlauf – unerwünschte Dämpfungen im Signal sind dabei nicht aufgetreten. Auch der von uns entwickelte Butterworth-Filter arbeitet zuverlässig. Die anfänglichen Fehler haben uns sensibilisiert und unsere Aufmerksamkeit für Details geschärft.

Das im Labor erworbene Wissen wird uns auch in zukünftigen Projekten von Nutzen sein, insbesondere beim Umgang mit ähnlichen Problemstellungen.

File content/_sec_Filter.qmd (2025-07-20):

# Schaltungsentwurf des Biquad-Filters

Im Folgenden wird die praktische Umsetzung des Biquad-Filters beschrieben. Der Schwerpunkt liegt auf dem gewählten Schaltungsaufbau, der Dimensionierung der Bauteile und der Umsetzung auf dem ASLK Pro Board.

Die universelle Biquad-Topologie lässt sich aus einfachen OP-Amp-Bausteinen aufbauen. Die jeweiligen Teilfilter (Tiefpass, Hochpass, Bandpass, Bandsperre) ergeben sich durch Kombinationen der Grundschaltungen und deren Übertragungsfunktionen.

### Der invertierende Verstärker {.unnumbered}

Die erste Grundschaltung ist der **invertierende Verstärker**, dessen Schaltung in @fig-invopamp gezeigt ist. Ein idealer OP-Amp arbeitet hier mit einem Eingangswiderstand $R_{1}$ und einem Rückkopplungswiderstand $R_{2}$:

Invertierender Verstärker [@reisch2007]

**Kurzbeschreibung:**  
- Der Eingang $V_{1}$ wird über $R_{1}$ auf den invertierenden Eingang geführt.  
- Der nichtinvertierende Eingang liegt auf Masse.  
- Über $R_{2}$ erfolgt die Rückkopplung vom Ausgang $V_{2}$ in den invertierenden Eingang.  

**Herleitung der Übertragungsfunktion**  
- Idealer OP-Amp: $V_{+} = V_{-}$, Eingangsströme vernachlässigbar.  
- Knotenregel am invertierenden Eingang ($V_{-} = 0$):

$$
\frac{V_{1} - V_{-}}{R_{1}} + \frac{V_{2} - V_{-}}{R_{2}} = 0
\quad\Longrightarrow\quad
\frac{V_{1}}{R_{1}} + \frac{V_{2}}{R_{2}} = 0.
$$

- Umstellen nach $\frac{V_{2}}{V_{1}}$:

$$
\frac{V_{2}}{V_{1}} = -\frac{R_{2}}{R_{1}}.
$$

Damit erhält man für den Spannungsübertragungsfaktor des invertierenden Verstärkers:

$$
H_{\text{inv}}(s) = \frac{V_{2}(s)}{V_{1}(s)} \approx -\frac{R_{2}}{R_{1}}.
$$

Das Minuszeichen veranschaulicht, dass die Ausgangsspannung eine entgegengesetzte Polarität zur Eingangsspannung aufweist. Diese Schaltungskonfiguration wird daher als invertierender Verstärker oder als Umkehrverstärker bezeichnet. [@reisch2007]

---

### Der Addierer {.unnumbered}

In der invertierenden Summierschaltung werden mehrere Eingangsspannungen $V_1, V_2, \dots, V_m$ jeweils über gleiche Widerstände $R$ an den invertierenden Eingang eines Operationsverstärkers geführt. Der nichtinvertierende Eingang liegt auf Masse, und der Rückkopplungswiderstand ist $R'$ wie im @fig-addopamp dargestellt ist.

Summierverstärker [@reisch2007]

**Herleitung der Übertragungsfunktion**  
1. Knotenregel am invertierenden Eingang (Potenzial $V_- = 0$):

$$
\sum_{i=1}^{m} \frac{V_i - V_-}{R} + \frac{V_{\text{out}} - V_-}{R'} = 0
\quad \Longrightarrow \quad
\sum_{i=1}^{m} \frac{V_i}{R} + \frac{V_{\text{out}}}{R'} = 0.
$$

2. Auflösen nach $\frac{V_{\text{out}}}{V_i}$:

$$
\frac{V_{\text{out}}}{R'} = - \sum_{i=1}^{m} \frac{V_i}{R}
\quad \Longrightarrow \quad
V_{\text{out}} = - R' \sum_{i=1}^{m} \frac{V_i}{R}.
$$

3. Für gleiche Widerstände ($R' = R$) vereinfacht sich das zu:

$$
V_{\text{out}} = - \bigl(V_1 + V_2 + \dots + V_m \bigr).
$$

Damit addiert der invertierende OP-Amp die Eingangsspannungen und invertiert das Vorzeichen.

---

### Der Invertierende Integrator {.unnumbered}

@fig-intopamp zeigt den klassischen invertierenden Integrator:  
- Eingangsspannung $V_1$ über Widerstand $R$ auf den invertierenden Eingang des OP-Amps.  
- Rückkopplung über Kondensator $C$ zwischen Ausgang $V_2$ und invertierendem Eingang.  
- Nichtinvertierender Eingang liegt auf Masse.

Der Integrierer [@reisch2007]

#### Zeitbereich {.unnumbered}

Mit der Annahme idealer OP-Amp-Eingänge ($V_{-} = V_{+} = 0$, $I_{-} = 0$) gilt:  
1. Strom durch $R$:  
   $$
   i_1 = \frac{v_1}{R}
   $$
2. Strom durch $C$:  
   $$
   i_2 = C \frac{dv_2}{dt}.
   $$
3. Knotenregel am invertierenden Eingang ($i_1 + i_2 = 0$):  
   $$
   \frac{v_1}{R} + C \frac{dv_2}{dt} = 0
   \quad\Longrightarrow\quad
   \frac{dv_2}{dt} = -\frac{1}{R C} v_1.
   $$
4. Durch Integrieren folgt:  
   $$
   v_2(t) = v_2(0) - \frac{1}{R C} \int_0^t v_1(t')\, dt'.
   $$

#### Laplace-Bereich {.unnumbered}

Im $s$-Bereich ersetzt man $\frac{d}{dt}$ durch $s$ und Anfangsbedingungen werden für die Übertragungsfunktion vernachlässigt. Dann gilt:  
1. Impedanzen:  
   $$
   Z_R = R, \quad Z_C = \frac{1}{s C}.
   $$
2. Knotenregel am invertierenden Eingang ($V_{-} = 0$):  
   $$
   \frac{V_1(s) - 0}{R} + \frac{V_2(s) - 0}{1/(s C)} = 0
   \quad\Longrightarrow\quad
   \frac{V_1(s)}{R} + s C V_2(s) = 0.
   $$
3. Nach $\frac{V_2(s)}{V_1(s)}$ auflösen:  
   $$
   s C V_2(s) = - \frac{V_1(s)}{R}
   \quad\Longrightarrow\quad
   \frac{V_2(s)}{V_1(s)} = - \frac{1}{s R C}.
   $$

Somit lautet die **Übertragungsfunktion des invertierenden Integrators**:

$$
H_{\mathrm{int}}(s) = \frac{V_2(s)}{V_1(s)} = - \frac{1}{s R C}.
$$

---

## Universeller aktiver Filter 2. Ordnung (Biquad)

Im Rahmen dieses Projekts wurde die Biquad-Schaltung nach dem **ASLK Pro Experiment 4** realisiert. Diese Experimentierplatine ermöglicht die einfache Umsetzung und Untersuchung verschiedener Filterkonfigurationen auf Basis von Operationsverstärkern.

Die folgende Abbildung zeigt die Schaltung des Biquad-Filters, wie sie im ASLK Pro Experiment 4 verwendet wurde:

Zweiter Ordnung Universeller Aktiver Filter.[@aslk]

### Auswahl und Berechnung der Bauteile {.unnumbered}

Ein wichtiger Aspekt der Realisierung der Schaltung, wie wir sie in @fig-biquadfilter gesehen haben, liegt in der gezielten Auswahl der **Widerstände (R)** und **Kondensatoren (C)**. Die genaue Dimensionierung dieser Bauteile bestimmt die wesentlichen Filtereigenschaften wie **Grenzfrequenz**, **Gütefaktor** und **Verstärkung**.

Diese Schaltung bildet die Grundlage für die nachfolgenden Messungen und Analysen im Projekt. Verschiedene Filtertypen können durch Anpassung der Einspeisepunkte und Bauteilwerte realisiert werden.

Die Auswahl der Bauteile für den Biquad-Filter erfolgte nach Vorgabe von zwei unterschiedlichen Kreisfrequenzen gemäß dem ASLK Pro Experiment 4:

- Für $\omega_0 = 1\,\text{KHz}$ ($f_0$ entspricht ca. $160\,\text{Hz}$) wurde $R = 1\,\text{k}\Omega$  und  $C = 1\,\mu\text{F}$ verwendet.

- Für $\omega_0 = 10\,\text{KHz}$ ($f_0$ entspricht ca. $1\,600\,\text{Hz}$) wurde $R = 1\,\text{k}\Omega$  und  $C = 0{,}1\,\mu\text{F}$ eingesetzt.

Die Dimensionierung basiert auf der Beziehung:
$$
\omega_0 = \frac{1}{RC}
$$

Damit ergibt sich für beide Fälle:

- $1\,\text{KHz} = \frac{1}{1\,\text{k}\Omega \cdot 1\,\mu\text{F}}$

- $10\,\text{KHZ} = \frac{1}{1\,\text{k}\Omega \cdot 0{,}1\,\mu\text{F}}$

Der Gütefaktor $Q$ wurde jeweils über das Verhältnis der Widerstände in den Rückkopplungszweigen angepasst, entsprechend den Vorgaben des Experiments.

Gütefaktor und zuständige Widerstand[@aslk]

Wie in Abbildung @fig-gütewiderstand dargestellt, wird der **Gütefaktor ($Q$)** des Filters maßgeblich durch den Widerstand im oberen Zweig der Schaltung (beschriftet mit "$Q \cdot R$") bestimmt. Dieser Widerstand legt, zusammen mit den verwendeten Kondensatoren, die Selektivität und Bandbreite des Filters fest. Um einen gewünschten Gütefaktor einzustellen, wird entsprechend der Wert dieses Widerstands angepasst.

Es ist zu beachten, dass bei einer Änderung des Gütefaktors in der Praxis häufig auch der Wert der Kondensatoren ($C$) mit angepasst werden muss. Nur so bleibt das Zusammenspiel von Mittenfrequenz ($\omega_0 = 1/RC$) und Gütefaktor ($Q$) für die gewünschte Filtercharakteristik erhalten.

Der sogenannte Gütewiderstand ist somit ein zentrales Element für die Feinanpassung der Filtereigenschaften bei universellen aktiven Filterschaltungen wie dem hier gezeigten Biquad-Filter.

Die in diesem Abschnitt verwendeten Bauteilwerte sind in der folgenden Tabelle übersichtlich zusammengefasst:

| $\omega_0$ [kHz] | $Q$ | $C$ [$\mu$F] | $R$ [k$\Omega$] | $Q \cdot R$  |
|---|-----|---|---|---|
| 1 | 1 | 1 | 1 | 1 |
| 10 | 10  | 0,1 | 1 | 10 |

: Dimensionierung der Bauteile {#tbl-dimensions}

Auf diese Weise konnte für beide Versuchsvarianten die gewünschte Kreisfrequenz sowie der zugehörige Gütefaktor realisiert werden.

## Simulation und Aufbau 

Nachdem die Bauteilwerte für die gewünschten Filtereigenschaften festgelegt waren, wie in @tbl-dimensions zu sehen, wurde die Schaltung in **KiCad 9.0** aufgebaut und simuliert.

Unser Ziel war es, ein Referenzmodell für das spätere praktische Verhalten des Filters zu erhalten. Mit Hilfe der Bode-Plot-Simulationen konnten die theoretisch zu erwartenden Amplituden- und Phasengänge überprüft werden.
Der Filterentwurf in KiCad kann wie in Abbildung @fig-Kicad dargestellt aufgebaut werden:

Simulationsaufbau für den aktiven Biquad-Filter in KiCad.[@kicad]

### Simulation der Schaltung (KiCad) {.unnumbered}

Die Simulation diente dazu, eventuelle Fehler oder Unstimmigkeiten im Schaltungsentwurf frühzeitig zu erkennen und die Praxistauglichkeit des gewählten Aufbaus zu beurteilen. So konnten vor dem Laboraufbau bereits wichtige Eigenschaften wie die Durchlasskurve, die Flankensteilheit und das Verhalten des Filters bei verschiedenen Gütefaktoren visualisiert und bewertet werden. Die aus der Simulation gewonnenen Frequenzgänge bilden die Grundlage für den späteren Vergleich mit den Messergebnissen am realen Aufbau.
Die Ergebnisse der simulierten Schaltung sind in den folgenden Plots dargestellt:

#### für $Q = 1$ {.unnumbered}

Bode-Plot der simulierten Biquad-Schaltung für $Q = 1$.

#### für $Q = 10$ {.unnumbered}

Bode-Plot der simulierten Biquad-Schaltung für $Q = 10$.

Wie in den Abbildungen @fig-bodeQ1 und @fig-bodeQ10 zu erkennen ist, stimmen die simulierten Amplituden- und Phasengänge gut mit den theoretisch erwarteten Kurven überein. Die Filter zeigen die charakteristischen Eigenschaften entsprechend der gewählten Bauteilwerte und Gütefaktoren.

Um einen besseren Vergleich zu ermöglichen, sind in den folgenden Abbildungen die theoretischen Amplituden- und Phasengänge dargestellt. Diese Kurven wurden dem ASLK Pro Manual entnommen und dienen als Referenz, um die Übereinstimmung zwischen Simulation und Theorie zu veranschaulichen.

Theoretische Amplituden- und Phasengänge aus dem ASLK Pro Manual [@aslk]

### Aufbau auf dem ASLK PRO Board {.unnumbered}
Aufbau von der Schaltung auf ASLK Board mit jumper Wires

Das Analog System Lab Kit Pro Board (ASLK Pro Board), ist ein Steckbrett auf welchem man Schaltungen simpel und ohne zu Löten umsetzten kann.
Mit hilfe dieses Steckbretts konnten wir die angegebene Schaltung aus dem Lab Manual, Labor 4, realisieren.
Doch damit die Umsetzung erfolgreich wurde, mussten wir zunächst die Spezifikationen für die Schaltung bestimmen, siehe @tbl-dimensions.

Daraufhin haben wir damit begonnen die Schaltung auf dem Steckbrett aufzubauen. Dies haben wir mit Kabeln und steckbaren Widerständen umgesetzt.

Aufbau auf dem ASLK PRO Board

Diese Schaltung haben wir mit einem RedPitaya verbunden, mit welchem wir die jeweiligen Filter messen konnten.

Nachdem wir die einezlnen Filter gemessen haben, setzten wir die Schaltung in KiCAD um, damit wir einen Vergleich für die Filter erhalten.

Zuletzt haben wir das Steckbrett noch für die Aufgaben aus dem Lab Manual benutzt, wodurch wie immer wieder leichte Veränderungen an der Schaltung vornehmen mussten.

## Butterworth 3. Ordnung: Entwurf und Erweiterung

Ein Butterworth-Filter zeichnet sich durch ein maximales Flachheitskriterium im Durchlassbereich aus und liefert eine steile Flanke von $-20\ \mathrm{dB/Dekade}$ pro Filterordnung ohne Überschwingen.  
Um im Rahmen dieses Experiments einen Tiefpass dritter Ordnung zu realisieren, wurde der Ausgang des bereits etablierten Zweitordnungs-Tiefpasses als Eingang für eine weitere Integratorstufe verwendet.

Butterworth Filter 3. Ordnung

#### Normale Integrator-Übertragungsfunktion: {.unnumbered}

Ein idealer invertierender Integrator mit Eingangswiderstand $R$ und Rückkopplungskondensator $C$ besitzt im $S$-Bereich die Übertragungsfunktion

$$
H_{\text{ideal}}(s) = \frac{V_{\mathrm{out}}(s)}{V_{\mathrm{in}}(s)} = - \frac{1}{s\,R\,C}.
$$

#### Integrator: {.unnumbered}

Um bei tiefen Frequenzen eine unendliche Gleichstromverstärkung zu vermeiden, wird in der Rückkopplung ein Widerstand $R_{10}$ parallel zu $C_{3}$ geschaltet. Die Impedanz des Feedback-Zweigs lautet

$$
Z_{f}(s) = \frac{R_{10}}{1 + s\,R_{10}\,C_{3}},
$$

und die Übertragungsfunktion des **Integrators** mit Eingangswiderstand $R_{9}$ ist

$$
H_{\text{int}}(s) = - \frac{Z_{f}(s)}{R_{9}} = - \frac{R_{10}}{R_{9}} \cdot \frac{1}{1 + s\,R_{10}\,C_{3}}.
$$

#### Zweitordnungs-Tiefpass: {.unnumbered}

Die bereits etablierte Tiefpass-Stufe zweiter Ordnung hat die Form

$$
H_{2}(s) = \frac{V_{03}(s)}{V_{\mathrm{in}}(s)} = \frac{H_{0}}{1 + \frac{s}{\omega_{0} Q} + \left(\frac{s}{\omega_{0}}\right)^2} = \frac{H_{0} \,\omega_{0}^{2}}{s^{2} + \frac{\omega_{0}}{Q} s + \omega_{0}^{2}}.
$$

#### Gesamtübertragungsfunktion: {.unnumbered}

Die Gesamtübertragungsfunktion des Butterworth-Tiefpasses 3. Ordnung ergibt sich durch Kaskadierung beider Stufen:

$$
H_{3}(s) = H_{2}(s) \times H_{\text{int}}(s) = \frac{H_{0} \,\omega_{0}^{2}}{s^{2} + \frac{\omega_{0}}{Q} s + \omega_{0}^{2}} \times \left(- \frac{R_{10}}{R_{9}} \cdot \frac{1}{1 + s\,R_{10}\,C_{3}} \right).
$$

Wählt man $\omega_{0} = \frac{1}{R_{10} C_{3}}$ und $\frac{R_{10}}{R_{9}} = 1$ , so vereinfacht sich die Gleichung zu

$$
H_{3}(s) = - \frac{H_{0} \,\omega_{0}^{3}}{(s^{2} + \frac{\omega_{0}}{Q} s + \omega_{0}^{2})(s + \omega_{0})}.
$$

Durch Ausmultiplizieren des Nenners erhält man die Normform:

$$
\boxed{
H_{\mathrm{BW3}}(s) = \frac{V_{\mathrm{out}}(s)}{V_{\mathrm{in}}(s)} = - \frac{H_{0} \,\omega_{0}^{3}}{s^{3} + \left(1 + \frac{1}{Q}\right) \omega_{0} s^{2} + \left(1 + \frac{1}{Q}\right) \omega_{0}^{2} s + \omega_{0}^{3}}
}.
$$

##### Simulationsergebnis des Butterworth-Tiefpasses 3. Ordnung {.unnumbered}
Die Abbildung zeigt den simulierten Amplituden- und Phasengang der realisierten Schaltung. Die charakteristische Flankensteilheit und das Übertragungsverhalten entsprechen den theoretischen Erwartungen für einen Butterworth-Filter dieser Ordnung. 

Butterworth Filter 3. Ordnung Simulation

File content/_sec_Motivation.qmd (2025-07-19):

# Motivation

In der Nachrichtentechnik sind Filter unverzichtbar. Insbesondere leistungsfähige, höhergradige Filter stoßen bei passiven RLC-Netzwerken jedoch schnell an ihre Grenzen: Spulen werden dabei sehr groß und teuer. Aufgrund ihrer Fertigungstoleranzen sind sie außerdem oft unzuverlässig bzw. nicht für präzise Filteranwendungen geeignet.  Aktive Filter auf Basis von Operationsverstärkern, Kondensatoren und Widerständen bieten hier klare Vorteile, da sich ihre Bauteilwerte einfacher und präziser herstellen und bestimmen lassen. Spulen lassen sich dabei durch Integratorschaltungen ersetzen.

Für das vorliegende Projekt greifen wir gezielt auf die Lerninhalte aus der Systemtheorie (Herleitung und Interpretation von Übertragungsfunktionen), der Elektronik (Verhalten von Operationsverstärkern als Integratoren und Addierer) und der digitalen Signalverarbeitung (Eigenschaften von Butterworth-, Tschebyscheff- und elliptischen Filtern) zurück. **So entsteht eine modulare Biquad-Schaltung, die alle vier Filtercharakteristiken auf einer Platine vereint** und zugleich durch eine zusätzliche Integrator-Stufe ein Butterworth-Filter höherer Ordnung realisiert. Diese durchgängige Lösung vermittelt sowohl theoretische Grundlagen als auch den kompletten Hardware-Design-Prozess – von der Simulation bis zur fertigen Leiterplatte – auf praxisnahe Weise.

Unser Biquad-Filterentwurf präsentiert sich in folgender Ausführung:

Fertige Leiterplatte mit universellem Biquad-Filterentwurf.

Im Folgenden werden das Verfahren, mit dem wir dieses Design entwickelt haben, sowie das zugrundeliegende Lernkonzept ausführlich dargestellt.

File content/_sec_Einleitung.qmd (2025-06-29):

# Einleitung

Ziel dieses Versuchs ist es, ein universelles analoges Biquad-Filter zu entwerfen, zu simulieren, praktisch aufzubauen und in ein professionelles Leiterplattendesign zu überführen. Die Grundlage bildet der Versuch 4 des ASLK PRO Manuals von Texas Instruments, in dem eine zweistufige aktive Filterstruktur mithilfe von Operationsverstärkern realisiert wird. Dabei wird das Verhalten typischer Filtertypen – darunter Tiefpass, Hochpass, Bandpass und Bandsperre – auf Basis einer sogenannten Biquad-Schaltung untersucht.

Zu Beginn wird die im Manual auf Seite 32 dargestellte Schaltung in der Simulationsumgebung KiCad modelliert, um ihr Frequenzverhalten zu analysieren und theoretisch zu validieren. Anschließend wird dieselbe Schaltung auf dem ASLK PRO Board unter Verwendung von Jumperkabeln praktisch realisiert und vermessen. Durch den Vergleich der simulierten und gemessenen Ergebnisse wird die Übereinstimmung zwischen Theorie und Praxis überprüft.

Nach erfolgreicher Realisierung der Grundschaltung wird das Filter um ein weiteres Modul ergänzt: Um einen Butterworth-Tiefpass dritter Ordnung zu erhalten, wird das Ausgangssignal der Tiefpass-Stufe (LPF) der Biquad-Schaltung genutzt, um einen zusätzlichen Integrator anzusteuern. Diese Kaskadierung dient der Erzeugung eines glatten Übergangs im Frequenzgang mit typischem Butterworth-Verhalten und stellt eine praxisrelevante Anwendung dar.

Im dritten Schritt wird die gesamte Schaltung – bestehend aus der ursprünglichen Biquad-Konfiguration sowie dem optionalen Butterworth-Modul – in KiCad als Leiterplattenlayout umgesetzt. Dabei wird darauf geachtet, die Filtercharakteristik durch gezielte Auswahl von Jumperverbindungen flexibel messbar zu gestalten und sowohl die Basis- als auch die Erweiterungsstruktur (Butterworth) in die Platine zu integrieren. Nach erfolgreichem Design wird die Platine gefertigt, bestückt und abschließend vermessen.

Durch diesen vollständigen Designzyklus wird ein praxisnahes Verständnis für den analogen Schaltungsentwurf, die Simulation sowie die Herausforderungen beim Layout und der Umsetzung eines funktionsfähigen Leiterplattenprototyps vermittelt.

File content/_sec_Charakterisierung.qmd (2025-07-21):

# Charakterisierung 

### Steckbrett {.unnumbered}

Wie häufig bei praktischen Versuchen traten auch hier zunächst unerwartete Probleme auf. Die Messergebnisse des ersten Steckbrett-Aufbaus wichen deutlich von den Simulationen ab. Trotz sorgfältiger Überprüfung der Schaltung – auch mit Unterstützung des Laboringenieurs – ließ sich kein offensichtlicher Fehler finden.

Um mögliche Fehlerquellen auszuschließen, wurde die Schaltung anschließend auf einem neuen Steckbrett ohne zusätzliche Kabelverlängerungen erneut aufgebaut. Nach diesem Neuaufbau stimmten die Messergebnisse mit den Simulationen überein. Dies deutet darauf hin, dass das ursprüngliche Steckbrett fehlerhaft war und die Ursache für die Abweichungen darstellte.

### Dämpfung {.unnumbered}

Das Steckbrett stellte jedoch nicht die einzige Herausforderung dar. Nach Durchführung der Messungen an den einzelnen Filterschaltungen wurde deutlich, dass eine Dämpfung von 20 dB vorliegt. Zur Verdeutlichung dieses Problems ist im Folgenden ein exemplarischer Plot dargestellt, in dem die 20 dB-Dämpfung sichtbar wird.

Bode-Plot des Tiefpassfilters, der eine Dämpfung von 20 dB aufweist.

Wie im Plot zu erkennen ist, liegt die Amplitude des Ausgangssignals etwa 20 dB unter dem erwarteten Wert. Dies deutet darauf hin, dass irgendwo in der Schaltung ein Fehler vorliegt, der zu einer unerwarteten Dämpfung führt. 

Bei der Fehlersuche fiel zunächst mit bloßem Auge kein Problem auf. Daher wurden die Widerstände systematisch mit einem Multimeter überprüft. Dabei stellte sich heraus, dass versehentlich ein $10\,\mathrm{k}\Omega$-Widerstand anstelle des vorgesehenen $1\,\mathrm{k}\Omega$-Widerstands verbaut worden war. Dieser Fehler entstand vermutlich im Zuge einer früheren Laboraufgabe.

Nach dem Austausch des Widerstands trat jedoch ein weiteres Problem auf: Die Dämpfung war zwar behoben, jedoch konnten die Messwerte mit dem RedPitaya im „Low Voltage“-Modus nicht korrekt erfasst werden, da dieser nur einen Messbereich von $-1\,\mathrm{V}$ bis $1\,\mathrm{V}$ abdeckt.

Nach Umstellung auf den „High Voltage“-Modus entsprachen die Messergebnisse schließlich den Simulationen. Damit konnte die Ursache für die unerwartete $20\,\mathrm{dB}$-Dämpfung erfolgreich identifiziert und behoben werden.

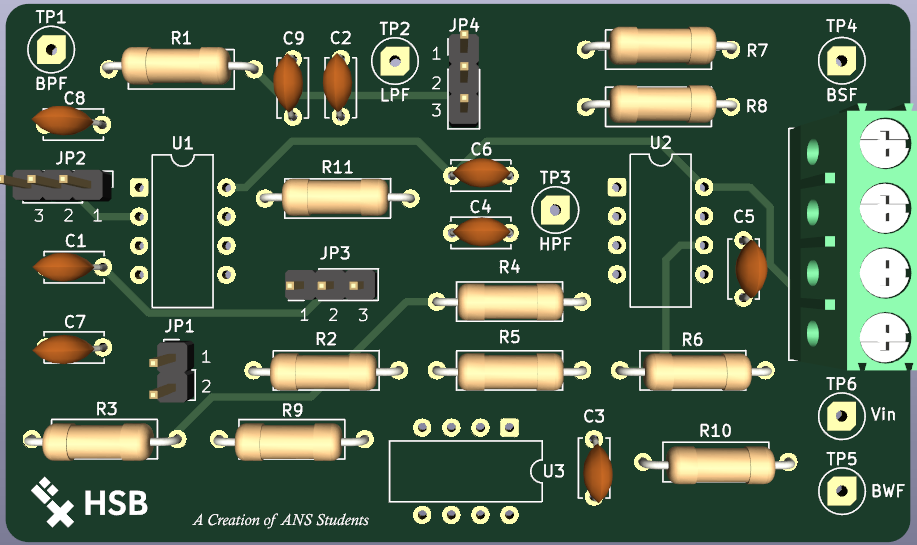
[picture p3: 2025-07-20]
_manuscript/images/pcbv2.png

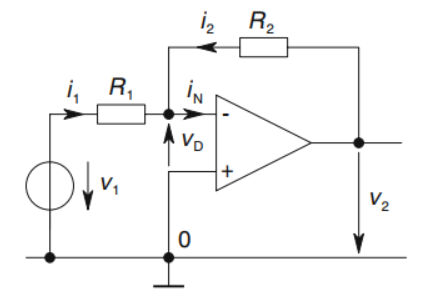
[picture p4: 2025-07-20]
_manuscript/images/invopamp.png

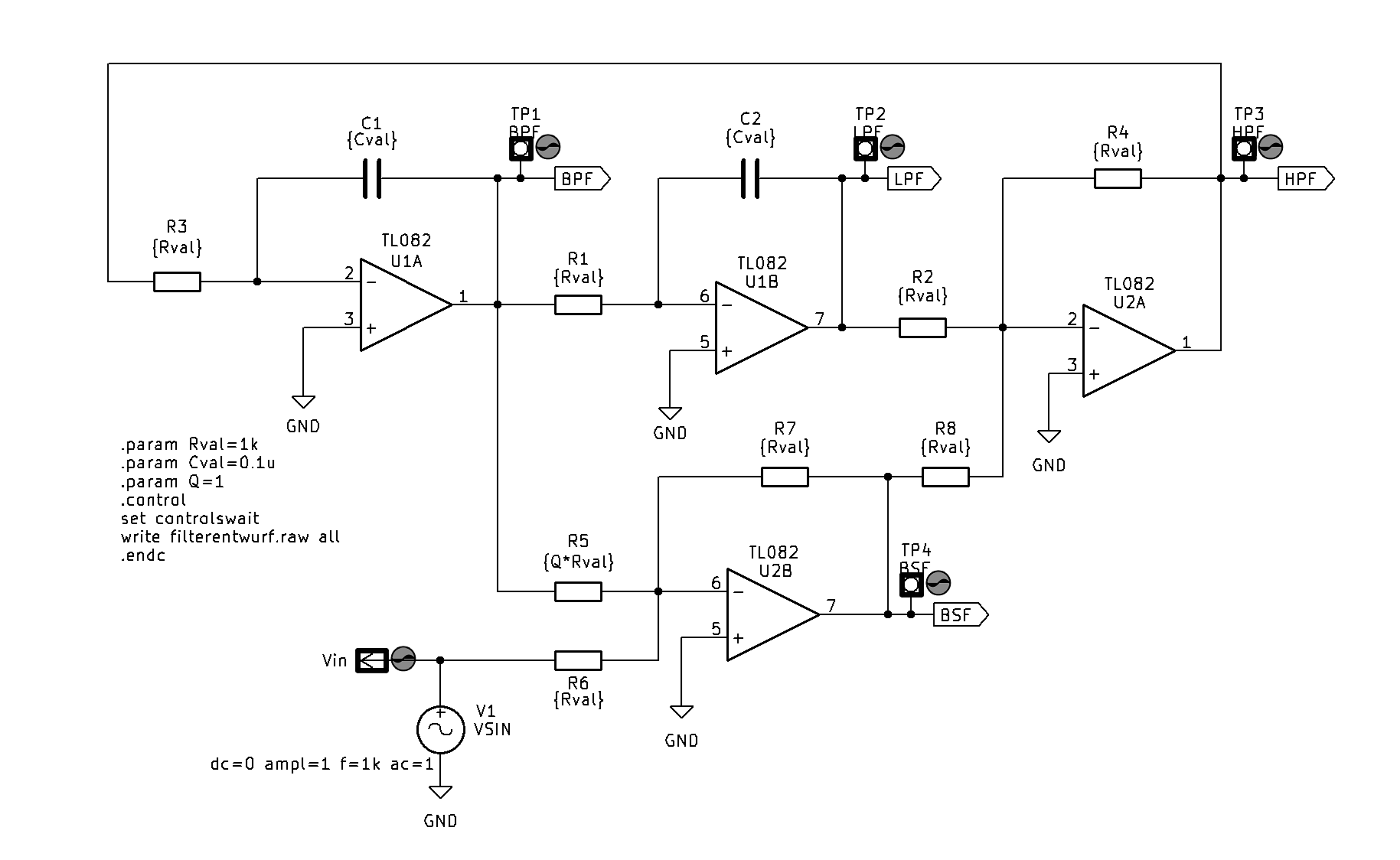
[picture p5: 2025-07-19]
_manuscript/images/Kicad_Schaltung_2.png

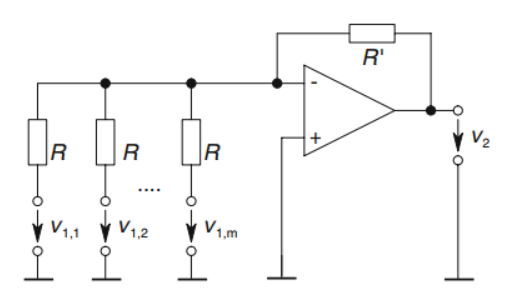
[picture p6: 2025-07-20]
images/addopamp.png

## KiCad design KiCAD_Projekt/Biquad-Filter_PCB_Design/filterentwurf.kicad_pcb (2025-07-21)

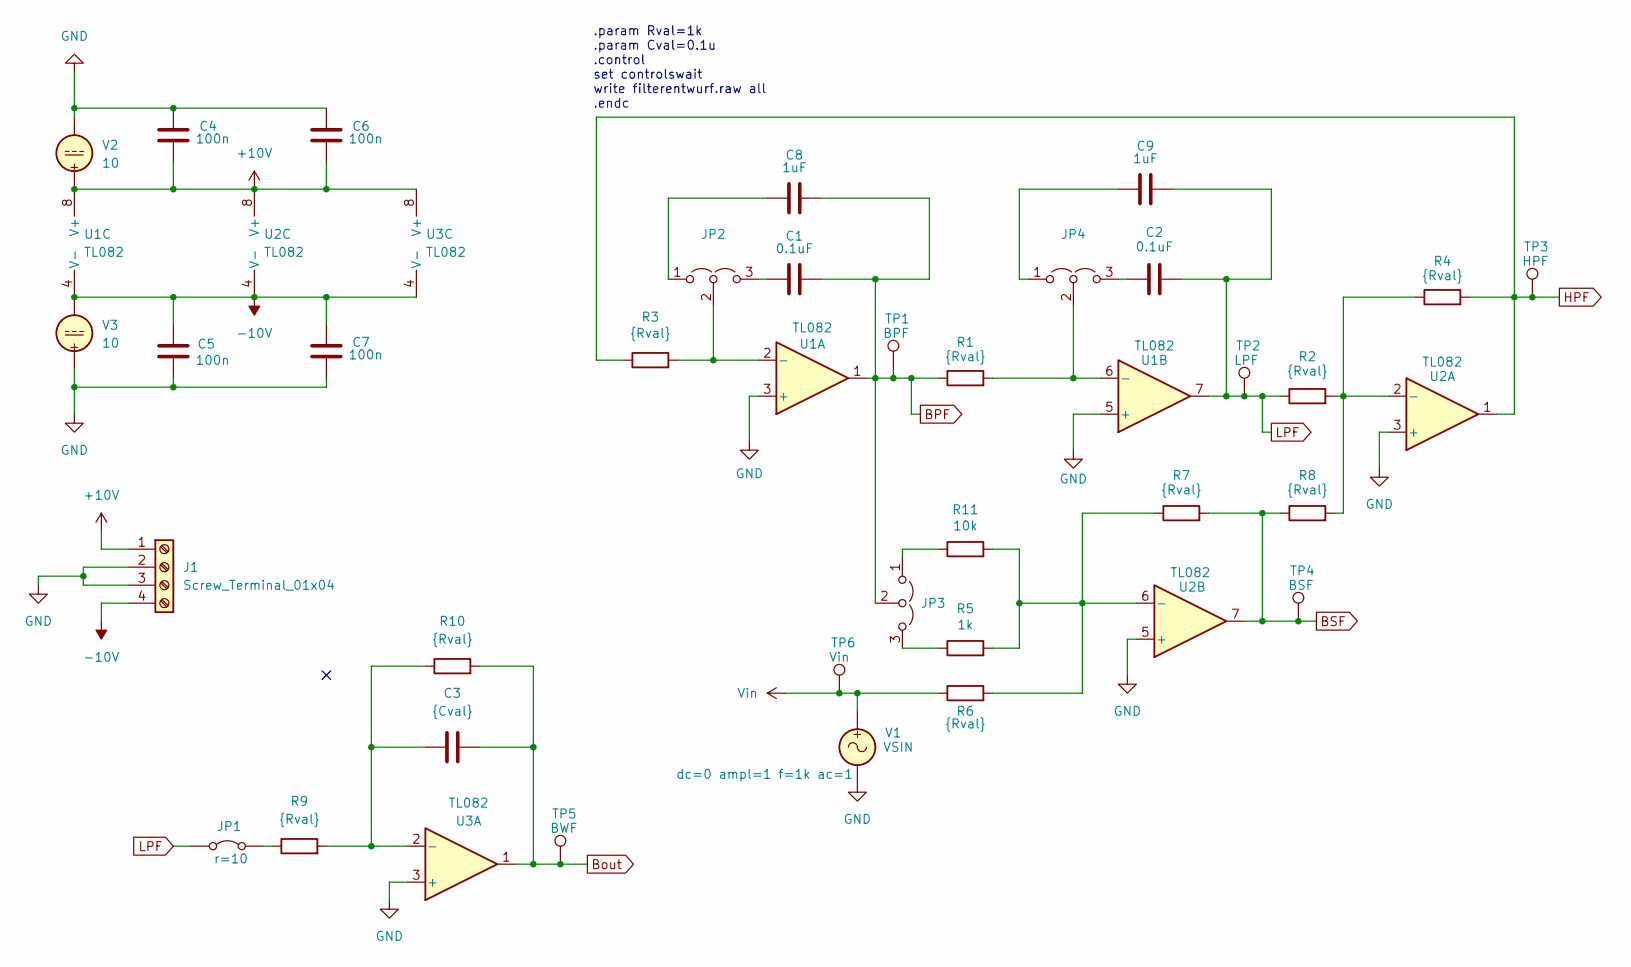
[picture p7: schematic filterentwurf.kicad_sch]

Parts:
C1, C2: 0.1uF; C_Disc_D5.0mm_W2.5mm_P5.00mm
C3: {Cval}; C_Disc_D5.0mm_W2.5mm_P5.00mm
C4, C5, C6, C7: 100n; C_Disc_D5.0mm_W2.5mm_P5.00mm
C8, C9: 1uF; C_Disc_D5.0mm_W2.5mm_P5.00mm
J1: Screw_Terminal_01x04; TerminalBlock_Phoenix_PT-1,5-4-5.0-H_1x04_P5.00mm_Horizontal
JP1: r=10; PinHeader_1x02_P2.54mm_Vertical
JP2, JP3, JP4: Jumper_3_Open; PinHeader_1x03_P2.54mm_Vertical
R1, R2, R3, R4, R6, R7, R8, R9, R10: {Rval}; R_Axial_DIN0309_L9.0mm_D3.2mm_P12.70mm_Horizontal
R5: 1k; R_Axial_DIN0309_L9.0mm_D3.2mm_P12.70mm_Horizontal
R11: 10k; R_Axial_DIN0309_L9.0mm_D3.2mm_P12.70mm_Horizontal
TP1: BPF; TestPoint
TP2: LPF; TestPoint
TP3: HPF; TestPoint
TP4: BSF; TestPoint
TP5: BWF; TestPoint
TP6: Vin; TestPoint
U1, U2, U3: TL082; CERDIP-8_W7.62mm_SideBrazed
V1: VSIN
V2, V3: 10

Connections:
+10V: C4.2, C6.2, J1.1, U1.8 (V+), U2.8 (V+), U3.8 (V+), V2.1
-10V: C5.1, C7.1, J1.4, U1.4 (V-), U2.4 (V-), U3.4 (V-), V3.2
BPF: C1.2, C8.2, JP3.2 (C), R1.1, TP1.1, U1.1
BSF: R7.2, R8.1, TP4.1, U2.7
Bout: C3.1, R10.2, TP5.1, U3.1
GND: C4.1, C5.2, C6.1, C7.2, J1.2, J1.3, U1.3 (+), U1.5 (+), U2.3 (+), U2.5 (+), U3.3 (+), V1.2, V2.2, V3.1
HPF: R3.1, R4.2, TP3.1, U2.1
LPF: C2.2, C9.2, JP1.1 (A), R2.1, TP2.1, U1.7
unnamed: JP1.2 (B), R9.1
unnamed: C8.1, JP2.1 (A)
unnamed: C1.1, JP2.3 (B)
unnamed: JP2.2 (C), R3.2, U1.2 (-)
unnamed: JP3.1 (A), R11.1
unnamed: JP3.3 (B), R5.1
unnamed: C9.1, JP4.1 (A)
unnamed: C2.1, JP4.3 (B)
unnamed: JP4.2 (C), R1.2, U1.6 (-)
unnamed: R2.2, R4.1, R8.2, U2.2 (-)
unnamed: R5.2, R6.2, R7.1, R11.2, U2.6 (-)
unnamed: C3.2, R9.2, R10.1, U3.2 (-)
Vin: R6.1, TP6.1, V1.1

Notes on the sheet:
.param Rval=1k .param Cval=0.1u .control set controlswait write filterentwurf.raw all .endc

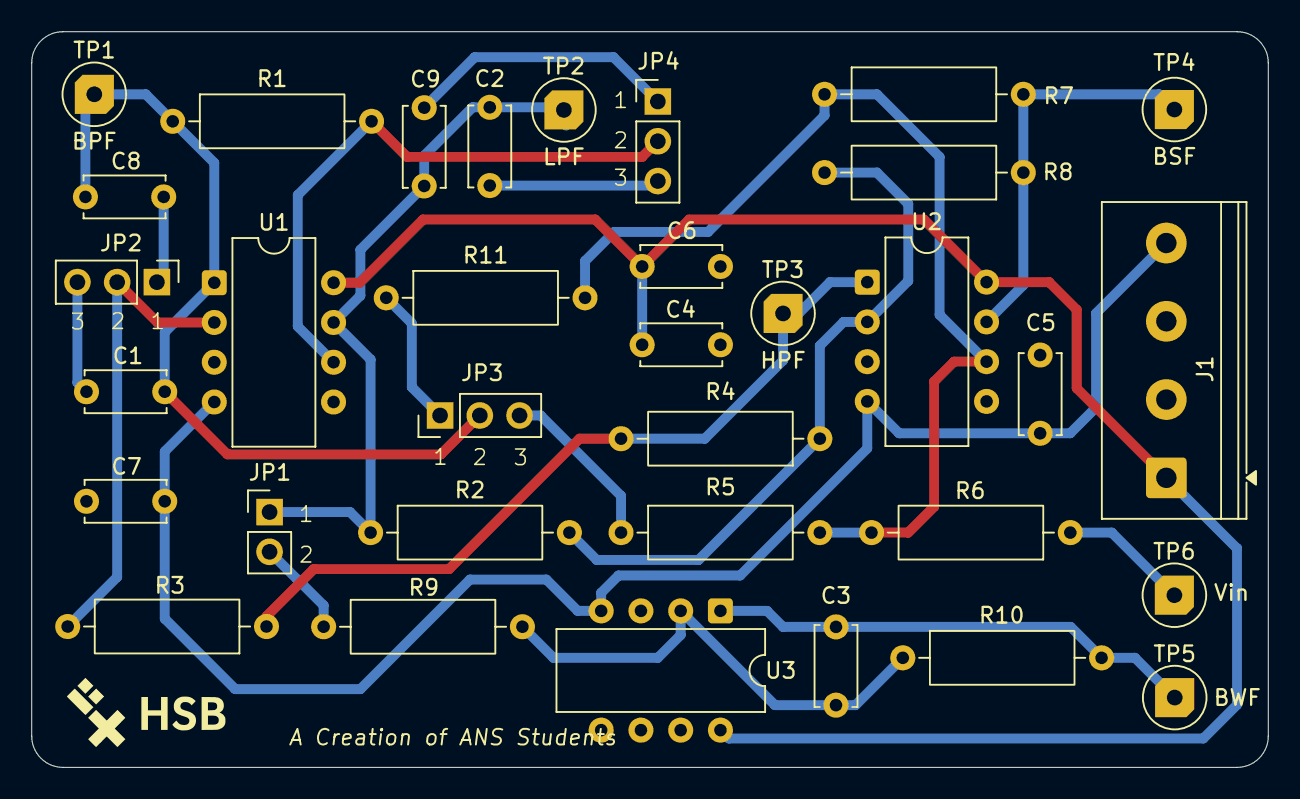
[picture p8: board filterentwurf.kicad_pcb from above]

Board: 2 copper layers, 79.0 x 47.0 mm, 34 parts (0 on the bottom side), 21 nets.

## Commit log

2025-06-30 Added Lab measurements
    [baData.csv, messwerte_sim.csv]
2025-07-01 Updated measurements
    [baData.csv]
2025-07-01 Added the updated measurments
    [baData.csv]
2025-07-08 Edited the file butter
    [baData.csv]
2025-07-08 PCB measurements added
    [baData.csv]
2025-07-13 Remove deleted Butter files
    [baData.csv]
2025-07-15 Butterworth simulation measurements added
    [messwerte_sim.csv]
2025-07-20 Bericht Änderungen
    [Q10_messwerte.csv, Q1_messwerte.csv]
2025-07-20 Data added
    [Butter_Tiefpass_sim_messwerte.csv]
2025-07-21 KiCAD Projekt
2025-07-21 Bericht und KiCAD angepasst
    [filterentwurf.kicad_pcb, filterentwurf.kicad_sch]
